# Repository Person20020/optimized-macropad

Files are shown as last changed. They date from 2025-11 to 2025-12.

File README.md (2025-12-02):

# Optimized Macropad

This macropad is built to be in the shape of the optimized compact layout for 17 squares within a larger square. It has 17 keys with rgb backlights. It uses QMK Vial to allow the keys to be customized.

Optimized Macropad

## PCB

There are two parts for the PCB. The main part holds the switches and the secondary small one allows the microcontroller to be attatched directly under in a more compact way.

Optimal_Macropad_PCB Render

PCB Layout

pcb

Schematic

schematic

## BOM

| Part | Quantity | Price | Link |
| --- | --- | --- | --- |
| Seeed Xiao RP2040 | 1 | $10 | [Amazon](https://a.co/d/aqcFIsh) |
| MX Switches | 17 | ~$0.50 each = $8.50 | |
| 1n4148 Diodes | 17 | $0.009 ea = $0.45 (50 min) | [LCSC](https://www.lcsc.com/product-detail/C402212.html) |
| SK6812 Mini E LEDs  | 17 | $1.71 | [LCSC](https://www.lcsc.com/product-detail/C5149201.html)  |
| Header Pins 1x7 | 2 | $0 | Comes with Xiao |
| Header Pins 1x6 | 2 | $0.25 (5 min order) | [LCSC](https://www.lcsc.com/product-detail/C42431804.html) |
| m3x12 mm Screws | 4 | $6.39 (pack of 120) | [Amazon](https://a.co/d/36DvsYz) |
| m3 Heat Set Inserts | 4 | $5.59 (pack of 100) | [Amazon](https://a.co/d/d310qRA) |
| Total Parts Price | | ~$32.89 | |

PCBs cost $8.40.

Total cost: ~$41.29

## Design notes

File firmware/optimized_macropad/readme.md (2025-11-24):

# optimized_macropad

optimized_macropad

*A short description of the keyboard/project*

* Keyboard Maintainer: [Koji Ino](https://github.com/Person20020)
* Hardware Supported: *The PCBs, controllers supported*
* Hardware Availability: *Links to where you can find this hardware*

Make example for this keyboard (after setting up your build environment):

    make optimized_macropad:default

Flashing example for this keyboard:

    make optimized_macropad:default:flash

See the [build environment setup](https://docs.qmk.fm/#/getting_started_build_tools) and the [make instructions](https://docs.qmk.fm/#/getting_started_make_guide) for more information. Brand new to QMK? Start with our [Complete Newbs Guide](https://docs.qmk.fm/#/newbs).

## Bootloader

Enter the bootloader in 3 ways:

* **Bootmagic reset**: Hold down the key at (0,0) in the matrix (usually the top left key or Escape) and plug in the keyboard
* **Physical reset button**: Briefly press the button on the back of the PCB - some may have pads you must short instead
* **Keycode in layout**: Press the key mapped to `QK_BOOT` if it is available

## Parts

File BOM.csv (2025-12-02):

Part | Quantity | Price | Link
Seeed Xiao RP2040 | 1 | $10 | https://a.co/d/aqcFIsh
MX Switches | 17 | ~$0.50 each = $8.50
1n4148 Diodes | 17 | $0.009 ea = $0.45 (50 min) | https://www.lcsc.com/product-detail/C402212.html
SK6812 Mini E LEDs | 17 | $1.71 | https://www.lcsc.com/product-detail/C5149201.html
Header Pins 1x7 | 2 | $0 | Comes with Xiao
Header Pins 1x6 | 2 | $0.25 (5 min order) | https://www.lcsc.com/product-detail/C42431804.html
m3x12 mm Screws | 4 | $6.39 (pack of 120) | https://a.co/d/36DvsYz
m3 Heat Set Inserts | 4 | $5.59 (pack of 100) | https://a.co/d/d310qRA

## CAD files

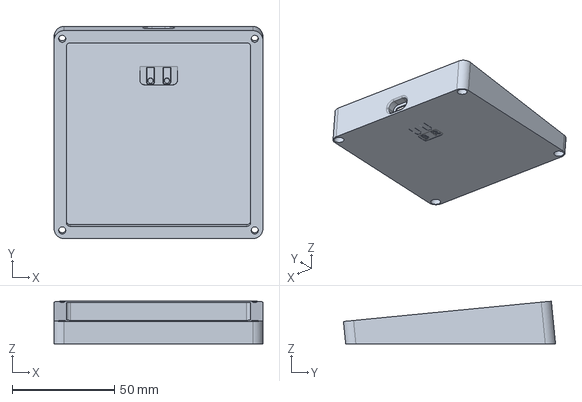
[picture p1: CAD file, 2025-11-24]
CAD/Optimized Macropad -- Bottom.step
102.3 x 103.9 x 20.9 mm

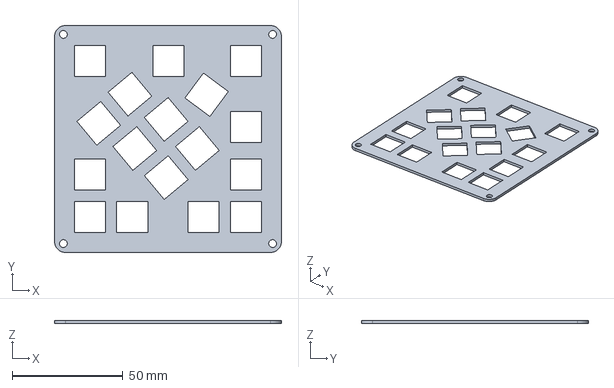
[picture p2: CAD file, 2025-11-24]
CAD/Optimized Macropad -- Plate.step
102.3 x 102.3 x 1.50 mm

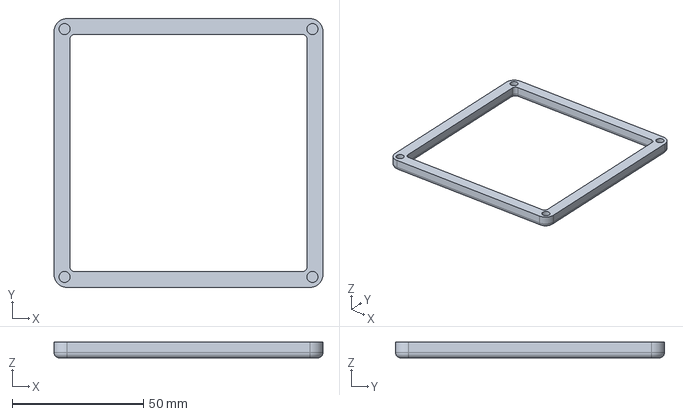
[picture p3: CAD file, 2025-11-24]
CAD/Optimized Macropad -- Top.step
102.3 x 102.3 x 6.00 mm

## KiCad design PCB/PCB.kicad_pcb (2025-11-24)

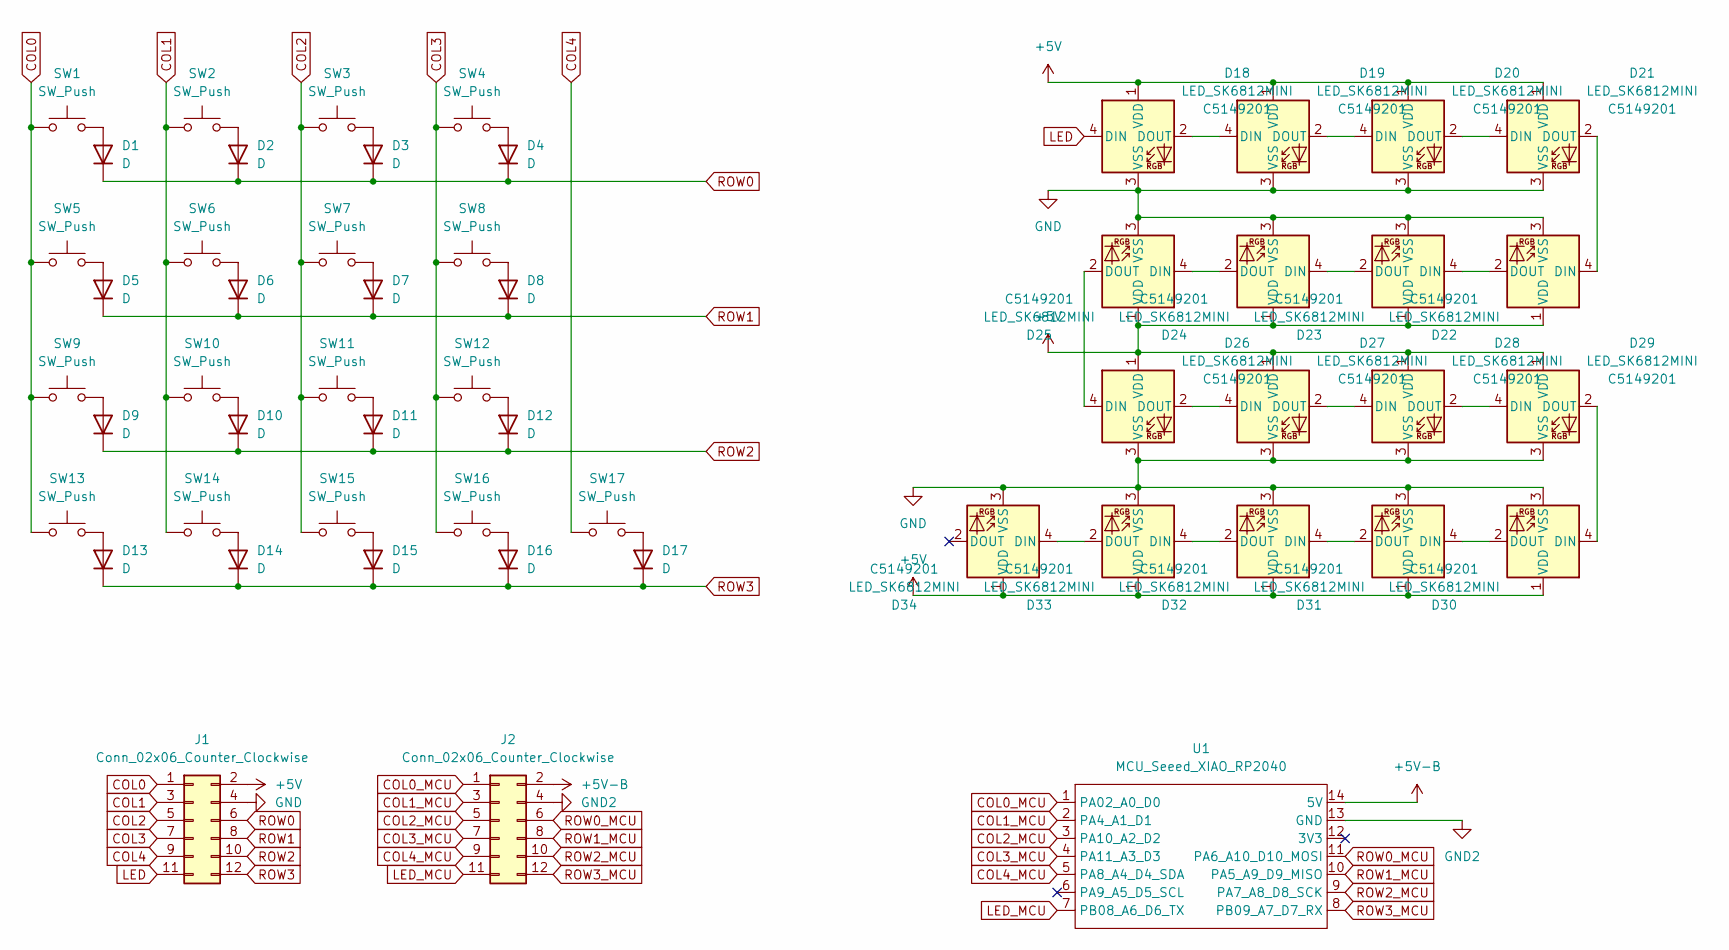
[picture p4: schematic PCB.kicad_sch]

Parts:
D1, D2, D3, D4, D5, D6, D7, D8, D9, D10, D11, D12, D13, D14, D15, D16, D17: D; D_DO-35_SOD27_P7.62mm_Horizontal
D18, D19, D20, D21, D22, D23, D24, D25, D26, D27, D28, D29, D30, D31, D32, D33, D34: LED_SK6812MINI; LCSC C5149201
J1, J2: Conn_02x06_Counter_Clockwise; PinHeader_2x06_P2.54mm_Vertical
SW1, SW2, SW3, SW4, SW5, SW6, SW7, SW8, SW9, SW10, SW11, SW12, SW13, SW14, SW15, SW16, SW17: SW_Push; MX_PCB_1.00u
U1: MCU_Seeed_XIAO_RP2040; Seeed_XIAO_RP2040

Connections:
+5V: D18.1 (VDD), D19.1 (VDD), D20.1 (VDD), D21.1 (VDD), D22.1 (VDD), D23.1 (VDD), D24.1 (VDD), D25.1 (VDD), D26.1 (VDD), D27.1 (VDD), D28.1 (VDD), D29.1 (VDD), D30.1 (VDD), D31.1 (VDD), D32.1 (VDD), D33.1 (VDD), D34.1 (VDD), J1.2
+5V-B: J2.2, U1.14 (5V)
COL0: J1.1, SW1.1, SW5.1, SW9.1, SW13.1
COL0_MCU: J2.1, U1.1 (PA02_A0_D0)
COL1: J1.3, SW2.1, SW6.1, SW10.1, SW14.1
COL1_MCU: J2.3, U1.2 (PA4_A1_D1)
COL2: J1.5, SW3.1, SW7.1, SW11.1, SW15.1
COL2_MCU: J2.5, U1.3 (PA10_A2_D2)
COL3: J1.7, SW4.1, SW8.1, SW12.1, SW16.1
COL3_MCU: J2.7, U1.4 (PA11_A3_D3)
COL4: J1.9, SW17.1
COL4_MCU: J2.9, U1.5 (PA8_A4_D4_SDA)
GND: D18.3 (VSS), D19.3 (VSS), D20.3 (VSS), D21.3 (VSS), D22.3 (VSS), D23.3 (VSS), D24.3 (VSS), D25.3 (VSS), D26.3 (VSS), D27.3 (VSS), D28.3 (VSS), D29.3 (VSS), D30.3 (VSS), D31.3 (VSS), D32.3 (VSS), D33.3 (VSS), D34.3 (VSS), J1.4
GND2: J2.4, U1.13 (GND)
LED: D18.4 (DIN), J1.11
LED_MCU: J2.11, U1.7 (PB08_A6_D6_TX)
unnamed: D1.2 (A), SW1.2
unnamed: D2.2 (A), SW2.2
unnamed: D3.2 (A), SW3.2
unnamed: D4.2 (A), SW4.2
unnamed: D5.2 (A), SW5.2
unnamed: D6.2 (A), SW6.2
unnamed: D7.2 (A), SW7.2
unnamed: D8.2 (A), SW8.2
unnamed: D9.2 (A), SW9.2
unnamed: D10.2 (A), SW10.2
unnamed: D11.2 (A), SW11.2
unnamed: D12.2 (A), SW12.2
unnamed: D13.2 (A), SW13.2
unnamed: D14.2 (A), SW14.2
unnamed: D15.2 (A), SW15.2
unnamed: D16.2 (A), SW16.2
unnamed: D17.2 (A), SW17.2
unnamed: D18.2 (DOUT), D19.4 (DIN)
unnamed: D19.2 (DOUT), D20.4 (DIN)
unnamed: D20.2 (DOUT), D21.4 (DIN)
unnamed: D21.2 (DOUT), D22.4 (DIN)
unnamed: D22.2 (DOUT), D23.4 (DIN)
unnamed: D23.2 (DOUT), D24.4 (DIN)
unnamed: D24.2 (DOUT), D25.4 (DIN)
unnamed: D25.2 (DOUT), D26.4 (DIN)
unnamed: D26.2 (DOUT), D27.4 (DIN)
unnamed: D27.2 (DOUT), D28.4 (DIN)
unnamed: D28.2 (DOUT), D29.4 (DIN)
unnamed: D29.2 (DOUT), D30.4 (DIN)
unnamed: D30.2 (DOUT), D31.4 (DIN)
unnamed: D31.2 (DOUT), D32.4 (DIN)
unnamed: D32.2 (DOUT), D33.4 (DIN)
unnamed: D33.2 (DOUT), D34.4 (DIN)
ROW0: D1.1 (K), D2.1 (K), D3.1 (K), D4.1 (K), J1.6
ROW0_MCU: J2.6, U1.11 (PA6_A10_D10_MOSI)
ROW1: D5.1 (K), D6.1 (K), D7.1 (K), D8.1 (K), J1.8
ROW1_MCU: J2.8, U1.10 (PA5_A9_D9_MISO)
ROW2: D9.1 (K), D10.1 (K), D11.1 (K), D12.1 (K), J1.10
ROW2_MCU: J2.10, U1.9 (PA7_A8_D8_SCK)
ROW3: D13.1 (K), D14.1 (K), D15.1 (K), D16.1 (K), D17.1 (K), J1.12
ROW3_MCU: J2.12, U1.8 (PB09_A7_D7_RX)

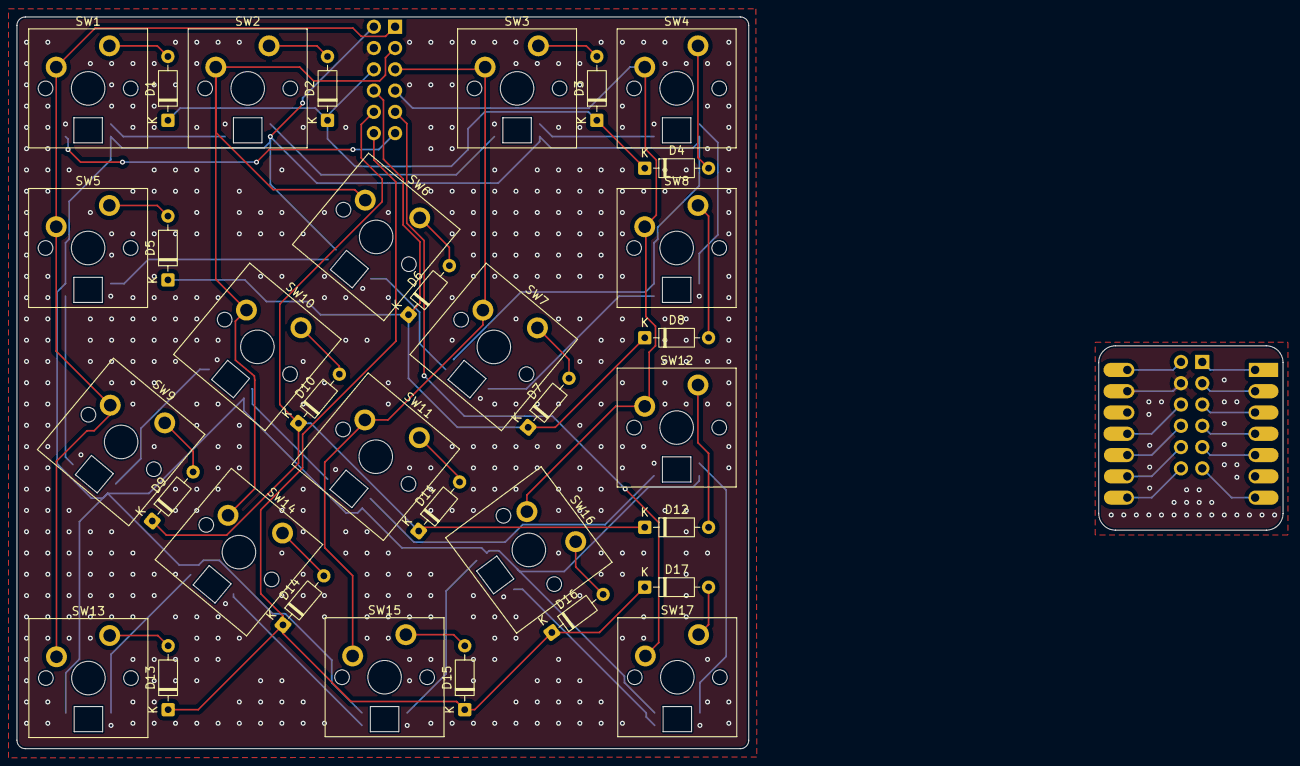
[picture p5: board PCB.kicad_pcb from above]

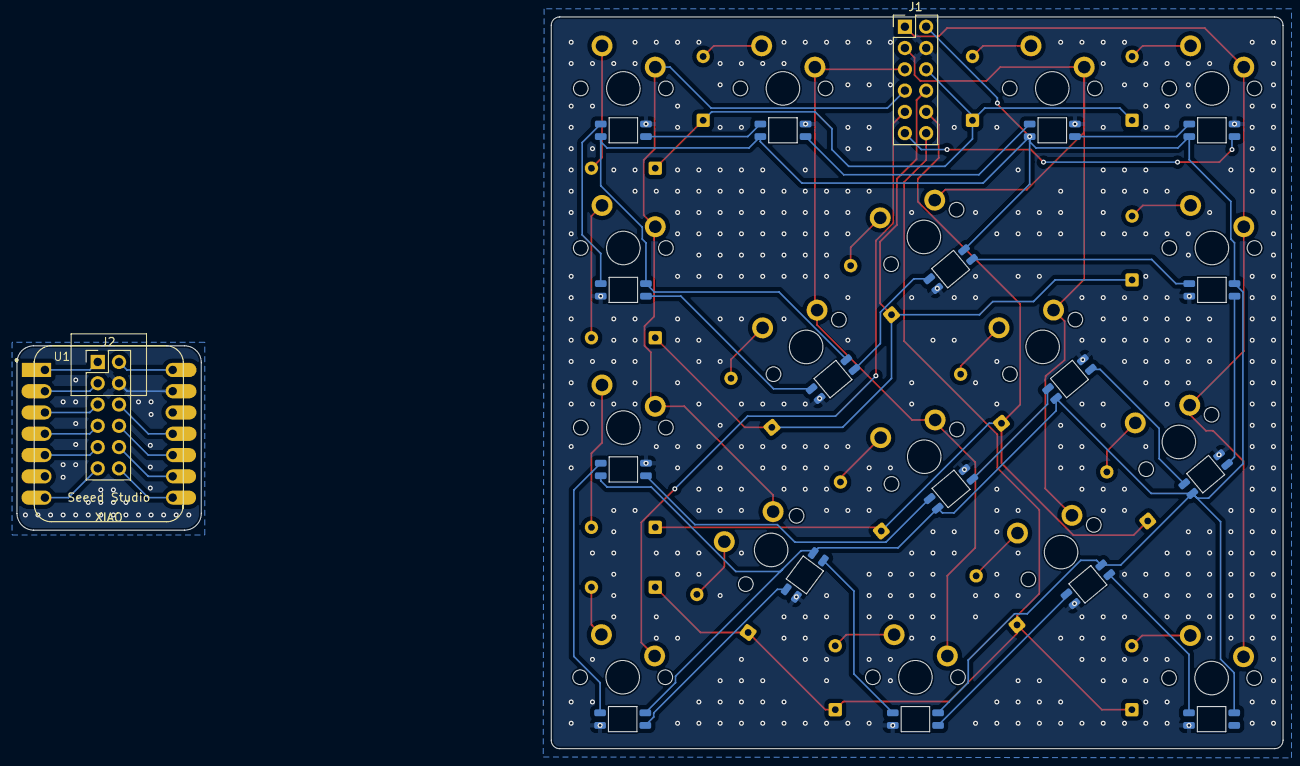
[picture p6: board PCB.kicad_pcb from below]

Board: 2 copper layers, 87.3 x 87.3 mm, 54 parts (20 on the bottom side), 57 nets.

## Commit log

2025-11-23 finished pcb + firmware
    [PCB.kicad_pcb, PCB.kicad_sch]
2025-11-24 added cad files and gerbers
    [Optimized Macropad -- Bottom.step, Optimized Macropad -- Plate.step, Optimized Macropad -- Top.step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]
2025-12-02 add bom
    [BOM.csv]
2025-12-02 fix pcb price
